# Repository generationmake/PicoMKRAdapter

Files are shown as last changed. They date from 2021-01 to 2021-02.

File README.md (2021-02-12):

# PicoMKRAdapter
adapter board to connect a Raspberry Pi Pico to an Arduino MKR Shield and vice versa

### Raspberry Pi Pico Side

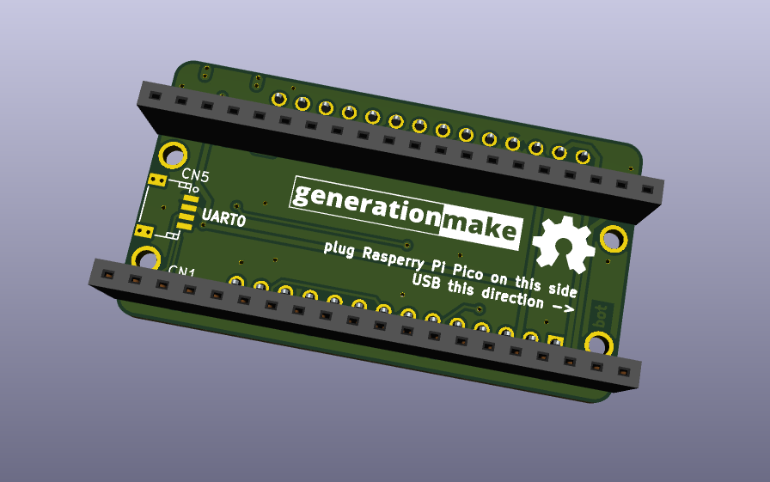
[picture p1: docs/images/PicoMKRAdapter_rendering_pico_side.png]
PicoMKRAdapter rendering pico side


### Arduino MKR Side

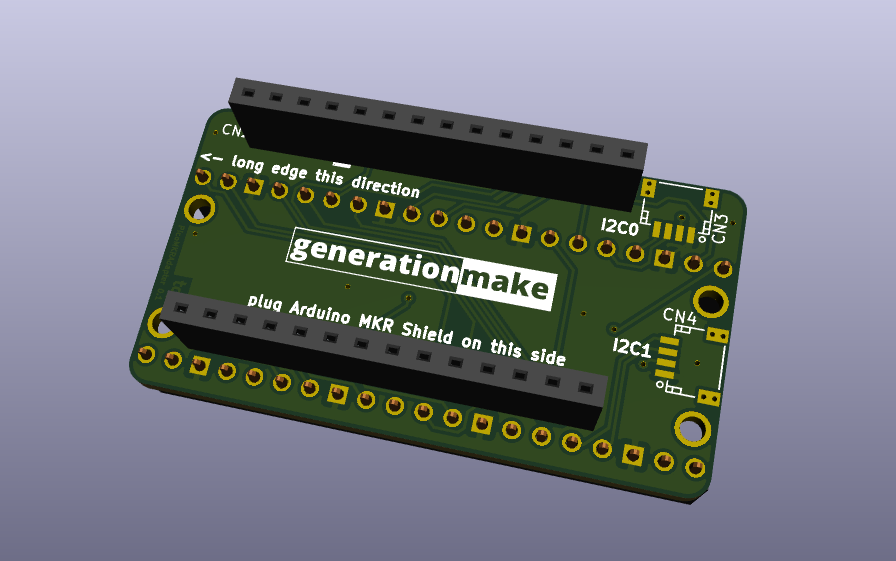
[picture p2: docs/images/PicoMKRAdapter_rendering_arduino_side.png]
PicoMKRAdapter rendering arduino side


## pin usage

### Arduino MKR connector CN2 vs Raspberry Pi Pico connector CN1

| **Pin** | **Pin Name** | **Pin Name** | **Pin** |
|:---:|:---:|:---:|:---:|
| x  | **Arduino MKR** | **Raspberry Pi Pico** |  x |
| 1 | AREF | ADC_VREF | 35 |
| 2 | DAC0/A0 | GP26/ADC0 | 31 |
| 3 | A1 | GP27/ADC1 | 32 |
| 4 | A2 | GP28/ADC2 | 34 |
| 5 | A3 | GP15 | 20 |
| 6 | A4 | GP22 | 29 |
| 7 | A5 | GP21 | 27 |
| 8 | A6 | GP20 | 26 |
| 9 | 0 | GP0 | 1 |
| 10 | 1 | GP1 | 2 |
| 11 | 2 | GP2 | 4 |
| 12 | 3 | GP3 | 5 |
| 13 | 4 | GP10 | 14 |
| 14 | 5 | GP5 | 7 |
| 15 | 6 | GP14 | 19 |
| 16 | 7 | GP11 | 15 |
| 17 | 8/MOSI | GP7 | 10 |
| 18 | 9/SCK | GP6 | 9 |
| 19 | 10/MISO | GP4 | 6 |
| 20 | 11/SDA | GP12/I2C0_SDA | 16 |
| 21 | 12/SCL | GP13/I2C0_SCL | 17 |
| 22 | 13/RX | GP9/UART1_RX | 12 |
| 23 | 14/TX | GP8/UART1_TX | 11 |
| 24 | RESET | RUN | 30 |
| 25 | GND | GND | 3..38 |
| 26 | VCC | 3V3 | 36 |
| 27 | VIN | VBUS | 40 |
| 28 | 5V0 | VSYS | 39 |

## PCB

### Top

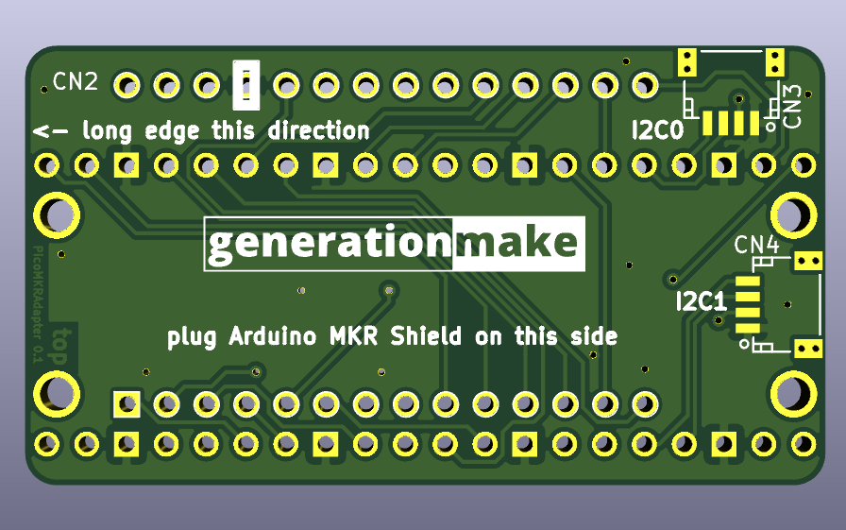
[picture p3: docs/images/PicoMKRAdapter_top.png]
PicoMKRAdapter PCB top


### Bottom

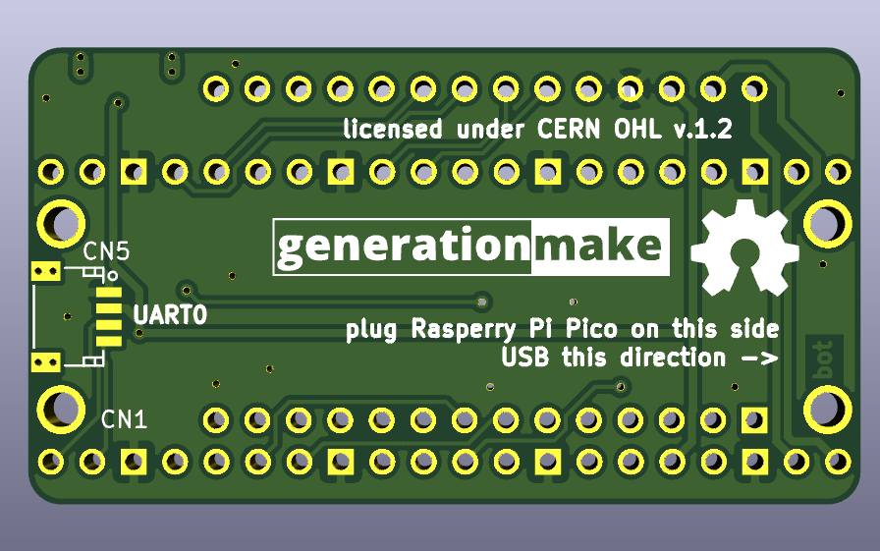
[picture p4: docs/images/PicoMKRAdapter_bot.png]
PicoMKRAdapter PCB bot


## License

This hardware is licensed under the CERN OHL v. 1.2

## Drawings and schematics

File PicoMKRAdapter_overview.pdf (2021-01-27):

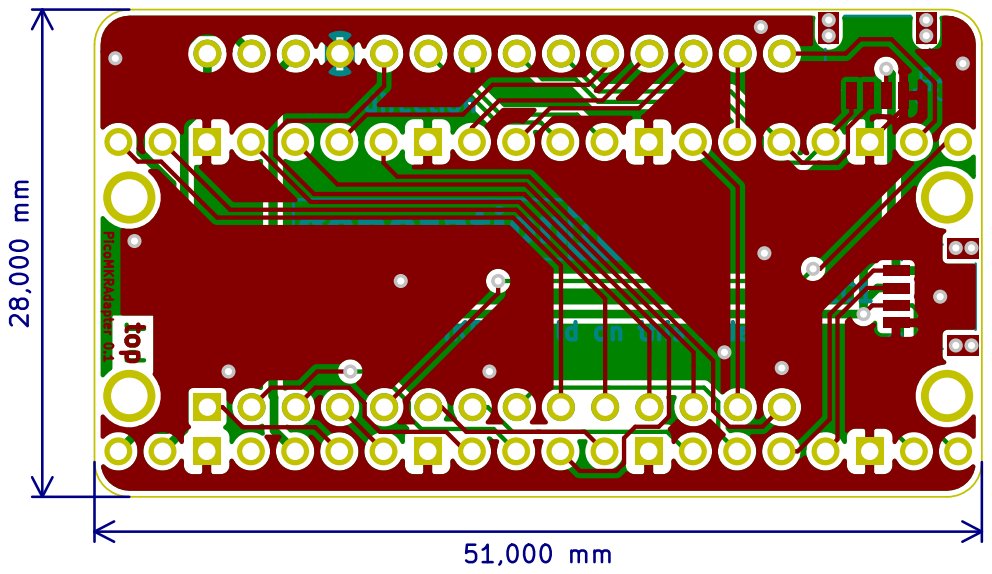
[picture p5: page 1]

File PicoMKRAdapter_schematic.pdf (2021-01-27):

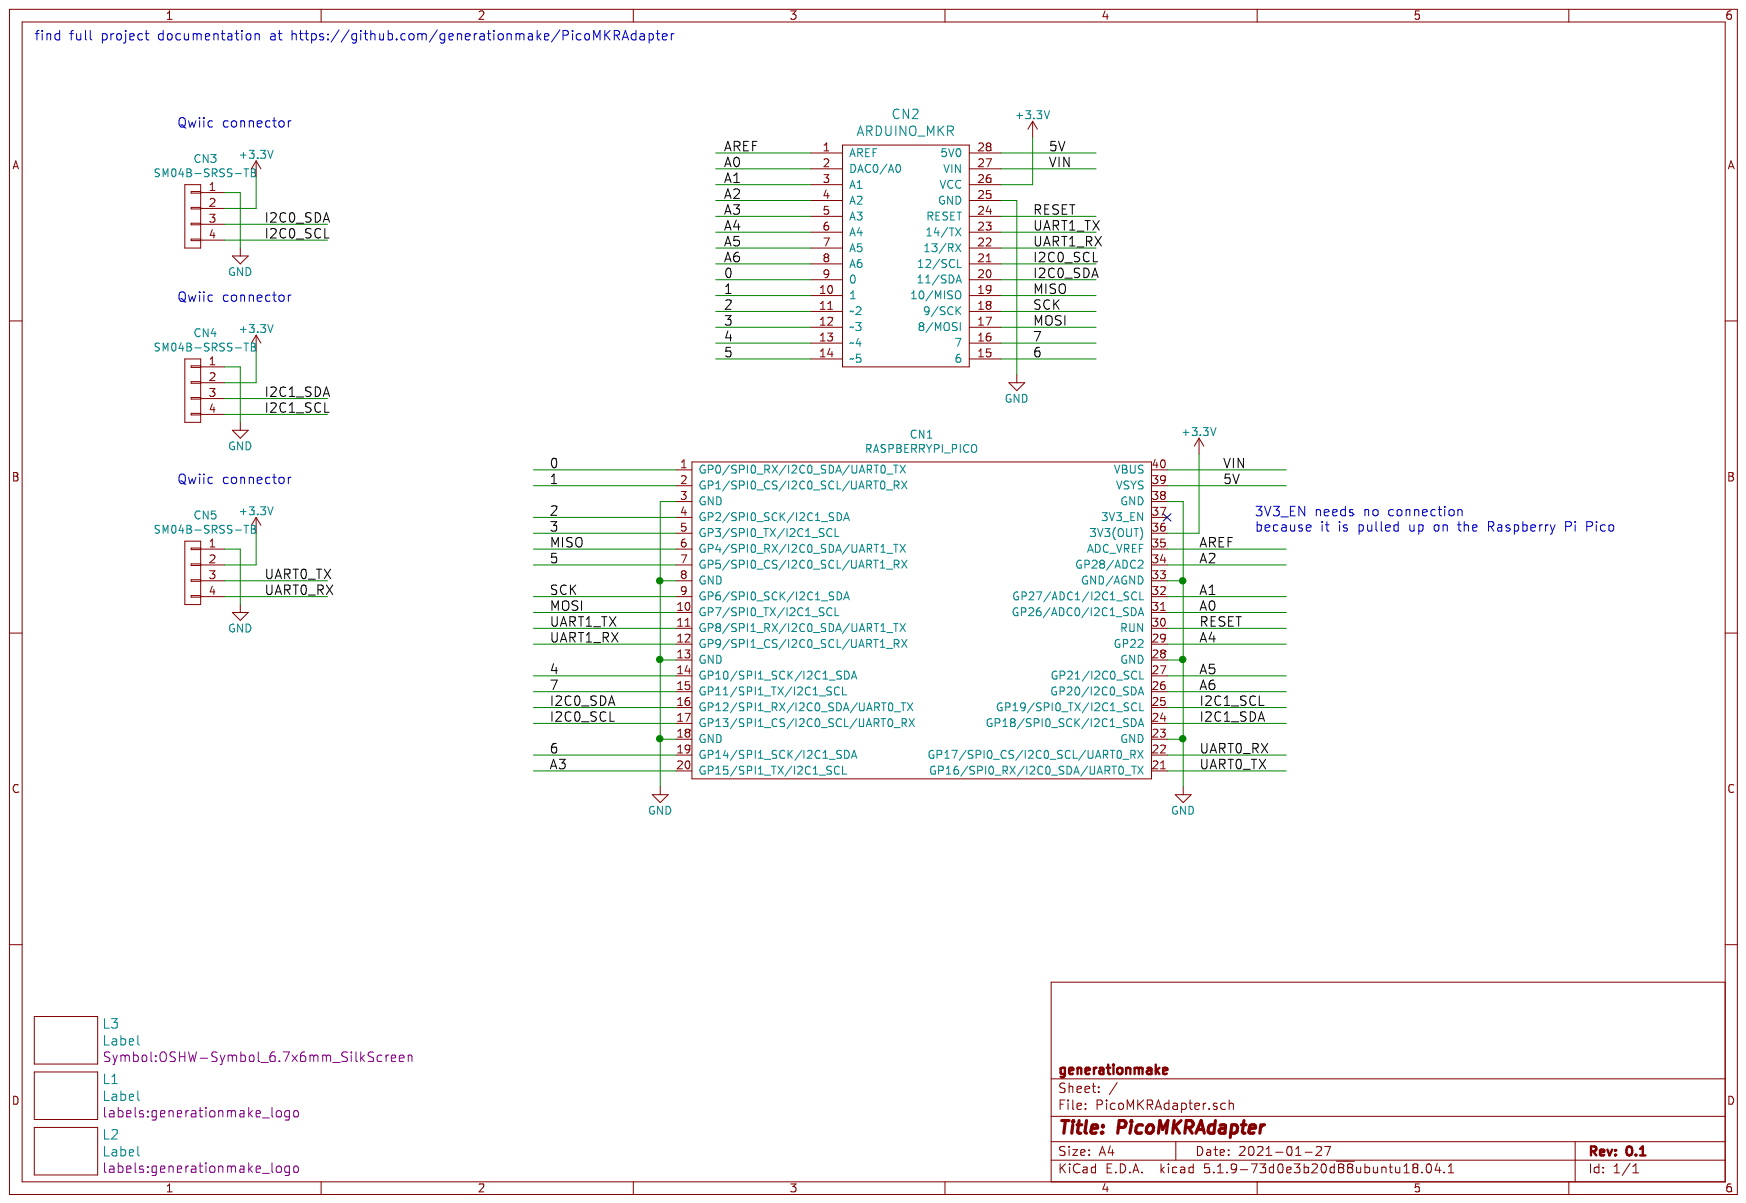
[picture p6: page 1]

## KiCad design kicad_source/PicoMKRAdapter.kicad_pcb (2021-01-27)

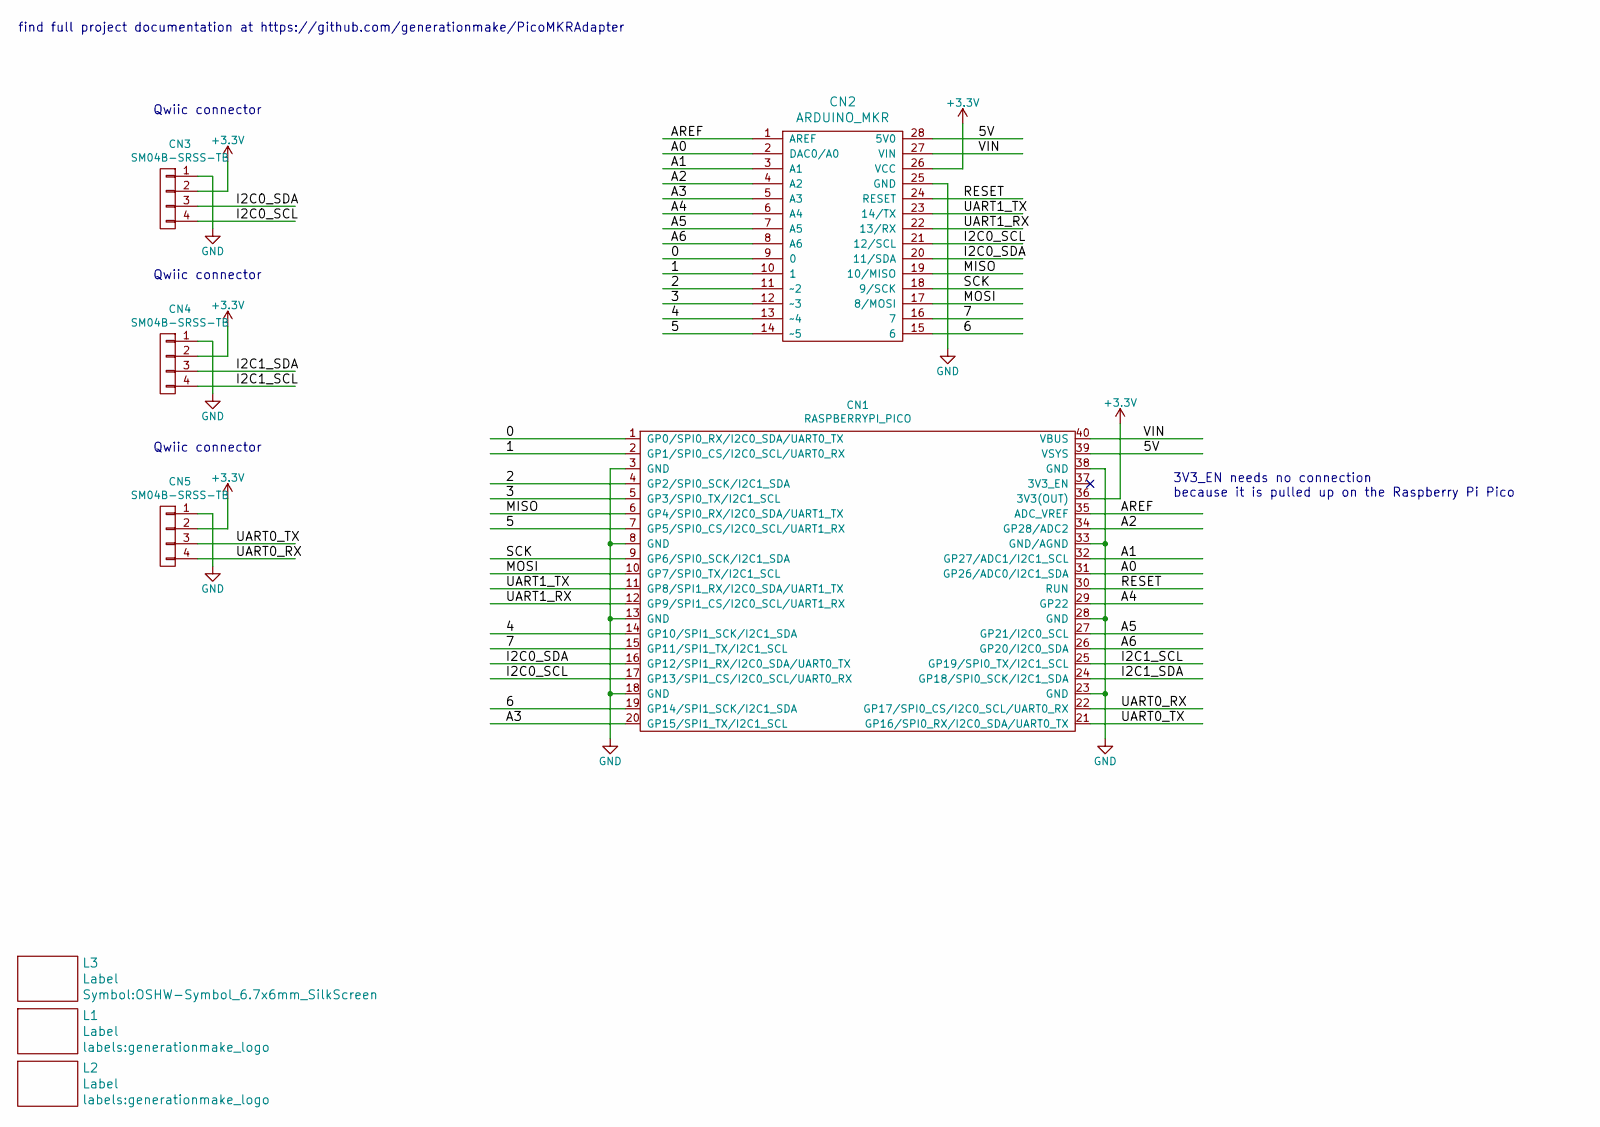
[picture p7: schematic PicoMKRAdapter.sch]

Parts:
CN1: RASPBERRYPI_PICO; RASPI_PICO
CN2: ARDUINO_MKR; ARDUINO_MKR_BASEBOARD
CN3, CN4, CN5: SM04B-SRSS-TB; Connectors_JST_SM04B-SRSS-TB
L1, L2: Label; generationmake_logo
L3: Label; OSHW-Symbol_6.7x6mm_SilkScreen

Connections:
+3V3: CN1.36 (3V3(OUT)), CN2.26 (VCC), CN3.2, CN4.2, CN5.2
/0: CN1.1 (GP0/SPI0_RX/I2C0_SDA/UART0_TX), CN2.9 (0)
/1: CN1.2 (GP1/SPI0_CS/I2C0_SCL/UART0_RX), CN2.10 (1)
/2: CN1.4 (GP2/SPI0_SCK/I2C1_SDA), CN2.11 (~~2)
/3: CN1.5 (GP3/SPI0_TX/I2C1_SCL), CN2.12 (~~3)
/4: CN1.14 (GP10/SPI1_SCK/I2C1_SDA), CN2.13 (~~4)
/5: CN1.7 (GP5/SPI0_CS/I2C0_SCL/UART1_RX), CN2.14 (~~5)
/5V: CN1.39 (VSYS), CN2.28 (5V0)
/6: CN1.19 (GP14/SPI1_SCK/I2C1_SDA), CN2.15 (6)
/7: CN1.15 (GP11/SPI1_TX/I2C1_SCL), CN2.16 (7)
/A0: CN1.31 (GP26/ADC0/I2C1_SDA), CN2.2 (DAC0/A0)
/A1: CN1.32 (GP27/ADC1/I2C1_SCL), CN2.3 (A1)
/A2: CN1.34 (GP28/ADC2), CN2.4 (A2)
/A3: CN1.20 (GP15/SPI1_TX/I2C1_SCL), CN2.5 (A3)
/A4: CN1.29 (GP22), CN2.6 (A4)
/A5: CN1.27 (GP21/I2C0_SCL), CN2.7 (A5)
/A6: CN1.26 (GP20/I2C0_SDA), CN2.8 (A6)
/AREF: CN1.35 (ADC_VREF), CN2.1 (AREF)
/I2C0_SCL: CN1.17 (GP13/SPI1_CS/I2C0_SCL/UART0_RX), CN2.21 (12/SCL), CN3.4
/I2C0_SDA: CN1.16 (GP12/SPI1_RX/I2C0_SDA/UART0_TX), CN2.20 (11/SDA), CN3.3
/I2C1_SCL: CN1.25 (GP19/SPI0_TX/I2C1_SCL), CN4.4
/I2C1_SDA: CN1.24 (GP18/SPI0_SCK/I2C1_SDA), CN4.3
/MISO: CN1.6 (GP4/SPI0_RX/I2C0_SDA/UART1_TX), CN2.19 (10/MISO)
/MOSI: CN1.10 (GP7/SPI0_TX/I2C1_SCL), CN2.17 (8/MOSI)
/RESET: CN1.30 (RUN), CN2.24 (RESET)
/SCK: CN1.9 (GP6/SPI0_SCK/I2C1_SDA), CN2.18 (9/SCK)
/UART0_RX: CN1.22 (GP17/SPI0_CS/I2C0_SCL/UART0_RX), CN5.4
/UART0_TX: CN1.21 (GP16/SPI0_RX/I2C0_SDA/UART0_TX), CN5.3
/UART1_RX: CN1.12 (GP9/SPI1_CS/I2C0_SCL/UART1_RX), CN2.22 (13/RX)
/UART1_TX: CN1.11 (GP8/SPI1_RX/I2C0_SDA/UART1_TX), CN2.23 (14/TX)
/VIN: CN1.40 (VBUS), CN2.27 (VIN)
GND: CN1.3 (GND), CN1.8 (GND), CN1.13 (GND), CN1.18 (GND), CN1.23 (GND), CN1.28 (GND), CN1.33 (GND/AGND), CN1.38 (GND), CN2.25 (GND), CN3.1, CN4.1, CN5.1

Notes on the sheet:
Qwiic connector
3V3_EN needs no connection because it is pulled up on the Raspberry Pi Pico
find full project documentation at https://github.com/generationmake/PicoMKRAdapter

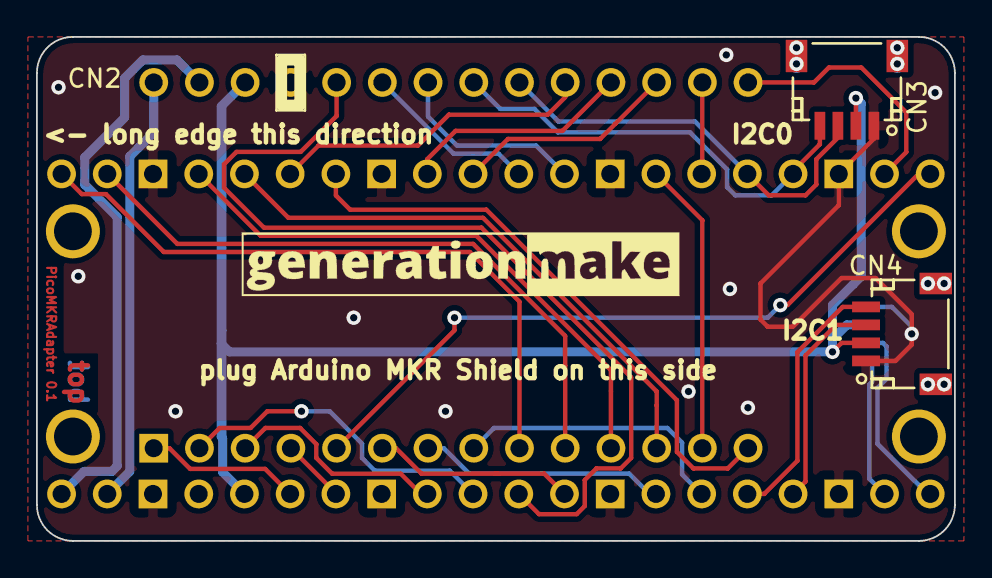
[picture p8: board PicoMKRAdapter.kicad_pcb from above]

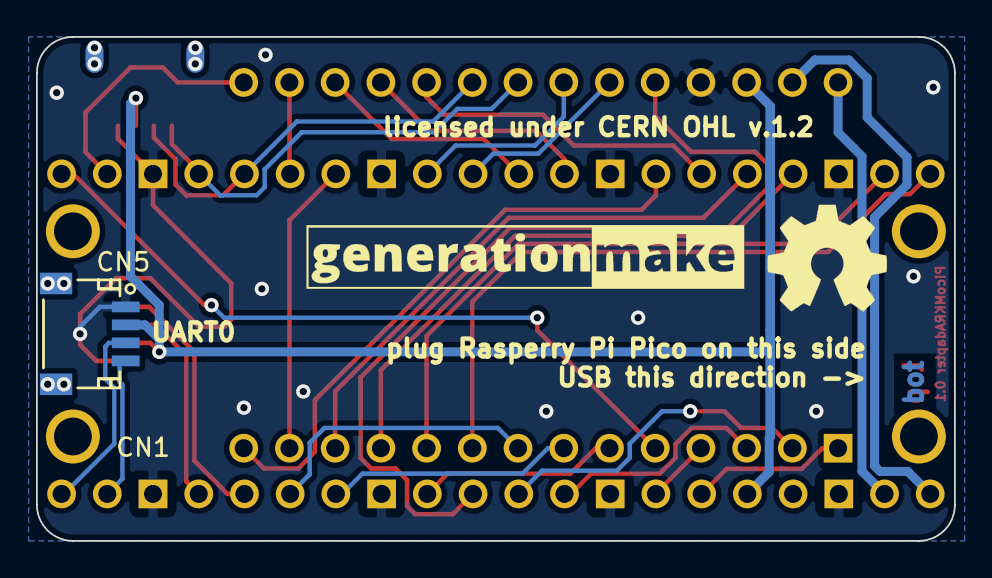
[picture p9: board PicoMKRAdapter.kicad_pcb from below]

Board: 2 copper layers, 51.0 x 28.0 mm, 8 parts (4 on the bottom side), 32 nets.

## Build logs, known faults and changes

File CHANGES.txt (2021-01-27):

PicoMKRAdapter - adapter board to connect a Raspberry Pi Pico to an Arduino MKR Shield and vice versa
see full project documentation at https://github.com/generationmake/PicoMKRAdapter

changes

version 0.1 - 2021-01-27
* prototype release

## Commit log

2021-01-23 added kicad project
    [PicoMKRAdapter.sch]
2021-01-24 added layout
    [PicoMKRAdapter.kicad_pcb, PicoMKRAdapter.sch]
2021-01-24 added schematic pdf
2021-01-25 updated layout and schematic, added i2c and serial connectors
    [PicoMKRAdapter.kicad_pcb, PicoMKRAdapter.sch]
2021-01-25 updated schematic pdf and images
2021-01-27 updated pico footprint
    [PicoMKRAdapter.kicad_pcb]
2021-01-27 connected RUN to RESET, added some labels
    [PicoMKRAdapter.kicad_pcb, PicoMKRAdapter.sch]
2021-01-27 updated pdfs and images
    [PicoMKRAdapter.kicad_pcb, PicoMKRAdapter.sch]
2021-02-12 added info on pin usage

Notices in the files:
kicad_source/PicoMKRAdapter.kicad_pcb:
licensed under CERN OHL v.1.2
